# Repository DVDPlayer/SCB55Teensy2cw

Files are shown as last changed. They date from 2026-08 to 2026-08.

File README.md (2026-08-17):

Disclaimer: I'm not a professional programmer or hardware engineer, so go easy on me, use at own risk!

Note: I know that the Teensy 2.0 is quite old, but I used it because I had it and for the challenge!
	Feel free to port it to another device. (Teensy 2.0 also has built-in support for USB-MIDI)

# 🚀 Teensy 2.0 Custom MIDI SBC-55 Controller Firmware (With Hardware Rev.1)

A playback prioritizing serial and USB MIDI firmware for the Teensy 2.0 platform featuring an OLED user interface, rotary encoder control (variable acceleration), Capital Tone Fallback (inverts bank# on fallback), drum and instrument tracking / setting per channel (354 instruments & 10 drum sets - all banks except 126), channel level settings (volume, reverb, chrous), global level settings (volume reverb, chrous), MT-32 emulation initialization (patch, pan, reverb, & pitch bend), display of MT-32 / SC-55 SysEx text messages, display of SC-55 SysEx graphics, send / receive GM & GS SysEx reset, 'analog' volume setting, all notes off Panic! feature, external (software driven) reset button, power-on reset of SCB-55, inactivity screen saver, and a dedicated MIDI hardware pipeline to the SCB-55 waveblaster module.  

Runs from USB (<350mA) or dedicated 6Vdc to 35Vdc input. (see Teensy MOD picture)

This repository contains only the core project firmware and hardware. All third-party dependencies are managed locally to keep the repository structure clean and as lightweight as possible.  

---

## 📦 Required Dependencies

Before compiling, make sure you have the following libraries installed via the Arduino Library Manager:
* **Adafruit_GFX** (OLED Core Graphics)
* **Adafruit_SSD1306** (OLED Driver)
* **Encoder** by Paul Stoffregen (Hardware Rotary Encoder tracking)

*Note: Core libraries (`Arduino.h`, `Wire.h`, `avr/pgmspace.h`, `util/delay.h`) are built into the Teensy / AVR toolchain and do not need to be installed manually.*

---

## 🛠️ Installation & Memory Optimization

To successfully fit the compiled firmware within the microcontroller's limited flash memory, you must disable the default Adafruit splash screen to save code space.

This project is shared under the **GNU GPLv3** license, and since third-party libraries are not hosted directly in this repository, you will need to apply the following optimizations to your local Arduino environment manually:

### Required Tweaks:
1. Locate your local Arduino libraries folder (usually found under `Documents/Arduino/libraries/`).
2. Open the `Adafruit_SSD1306` directory.
3. Open `Adafruit_SSD1306.h` in a text editor.
4. Locate the configuration lines near the top of the file and **uncomment** the splash logo macro definition to match this:
```   
   // Uncomment to disable Adafruit splash logo
   #define SSD1306_NO_SPLASH
```   
5. Open the Arduino `usb_api.h` in a text editor and change `#define USB_MIDI_SYSEX_MAX 64` to at least 79

(Location example: `c:\users\<username>\AppData\Local\Arduino15\packages\teensy\hardware\avr\1.61.0\cores\usb_midi`)

6. Go back one directory to the `cores` folder and open the `teensy` folder and Edit `HardwareSerial.cpp`

7. Find and change the following two lines: (Note: `RX_BUFFER_SIZE` was `64` which is too small for long SysEx)
```
#define RX_BUFFER_SIZE 128 
#define SERIAL1_TX_BUFFER_SIZE 256
```
8. After saving the above files you can compile the project in your Arduino IDE (`Board:Teensy2.0` `USB Type:MIDI`).

---

## 🔌 Hardware Pinout (Basic Info - or if not using my board design)

Connect your components to the **Teensy 2.0** board according to the pinout layout below:

| Component 		| Pin 		| Teensy 2.0 Pin| Notes |
| :--- | :---: | :---: | ---: |
| **SSD1306 OLED**	| GND 		| GND		| (Check pinout as some OLEDs are backwards!)|
|			| VCC 5V	| VCC 5V	|	|
| 			| SCL 		| **5**  (PD0)	| I2C Clock (`Wire.h`)|
| 			| SDA 		| **6**  (PD1)	| I2C Data  (`Wire.h`)|
|			|		|		|	|
| **Rotary Encoder**	| Pin A  	| **1**  (PB1)	| Main rotation pin|
| encoder module used	| Pin B  	| *24**  (PE6)	| Main rotation pin|
|			| Switch 	| **0**  (PB0)	| Encoder push-button switch|
|			| VCC		| VCC		|	|
|			| GND		| GND		|	|
|			|		|		|	|
| **Vol POT 10k-100k**	| Wiper Pin 	| **12** (PD7)	| 'Analog' Output Control (Volume potentiometer)|
| Right Pin		| VCC		| VCC		| (optional part)|
| Left  Pin		| GND		| GND		|	|
|			|		|		|	|
| **Reset Button** 	| Switch Pin 	| **10** (PC7)	| System Reset trigger|
|			| GND		| GND		| (optional part)|
|			|		|		|	|
| **Reset to SCB55**	| Reset Line 	| **2**  (PB2)	| Hardware reset line sent to SCB-55 - pin 26|
|			|		|		|	|
| **Serial MIDI RX** 	| MIDI IN Line	| **RX (Pin 7)**| (PD2) Hardware MIDI input (from H11L1+470Ω pull-up)|
|			|		|		|	|
| **SCB-55 MIDI RX** 	| MIDI OUT Line	| **TX (Pin 8)**| (PD3) MIDI stream to Roland SCB-55 - pin 4|

 Note: 	Pin numbers are programming numbers, add 2 for actual pin number except 24 = pin30, 12 = pin19.
	If you want to use external power and USB, the Teensy 2.0 must be modified. (see Teensy MOD picture)
	The SCB-55 also requires a +/-12V and +5 supply to run correctly along with L/R audio out.

		MIDI Input Example:
<p float="left">
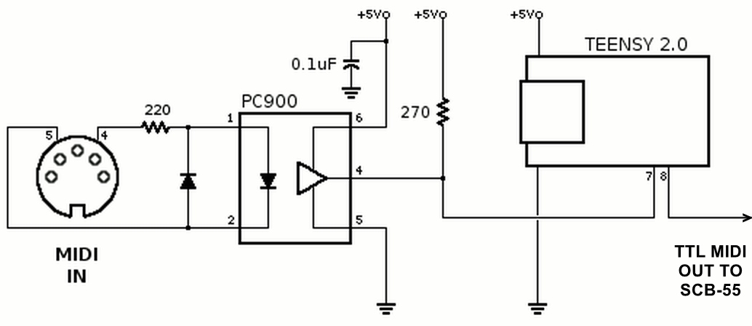
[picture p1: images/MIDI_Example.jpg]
   
</p>
(Note: The Ultra-cheap USB MIDI cables, with the treble clef, will corrupt all SysEx messages.)

---

## 🎹 MIDI & Serial Routing Architecture
* **Serial RX (Receive) :** Dedicated to handling incoming **MIDI In** streams.
* **USB MIDI  (Bi-directional):** to/from Teensy 2.0 (MIDI actions are echoed from UI to host PC)
* **Serial TX (Transmit):** Dedicated to delivering processed **MIDI data to the SCB-55** waveblaster module.

---

## 💻 MENUS, Teensy 2.0 Vusb mod, Rev1 Diode Mod (important) and other pictures

	Arduino IDE Settings
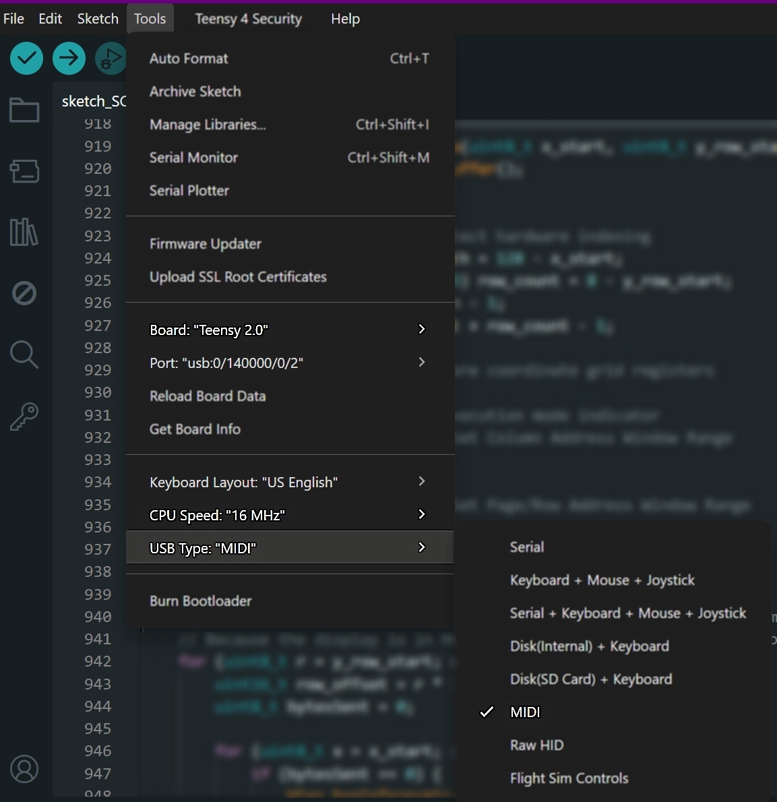
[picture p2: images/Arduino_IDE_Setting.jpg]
  
	 <b>Hardware</b> 
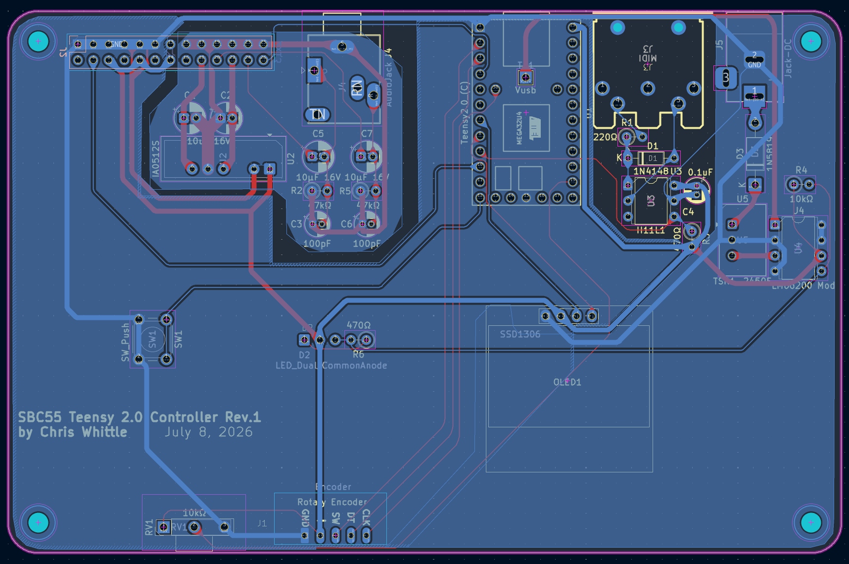
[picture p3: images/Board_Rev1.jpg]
   
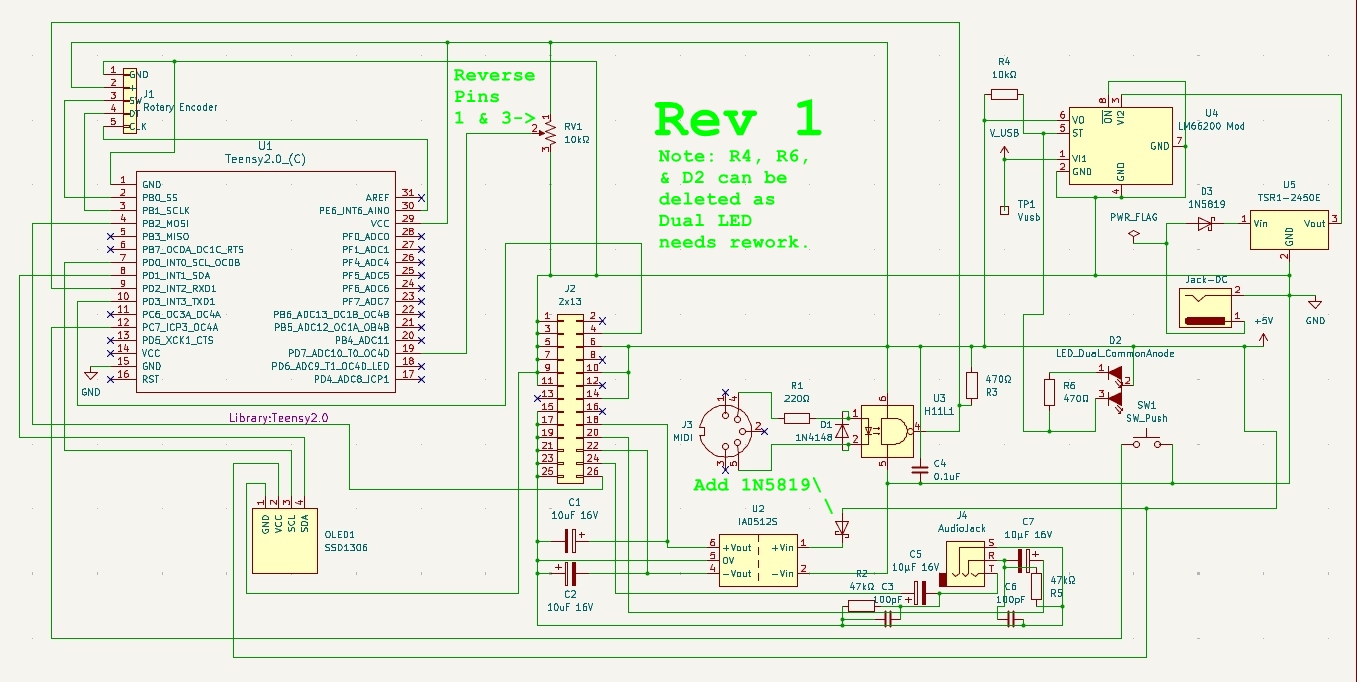
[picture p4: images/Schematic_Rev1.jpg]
   
	 <b>User Interface</b> 

| | |
| :---: | :---: |
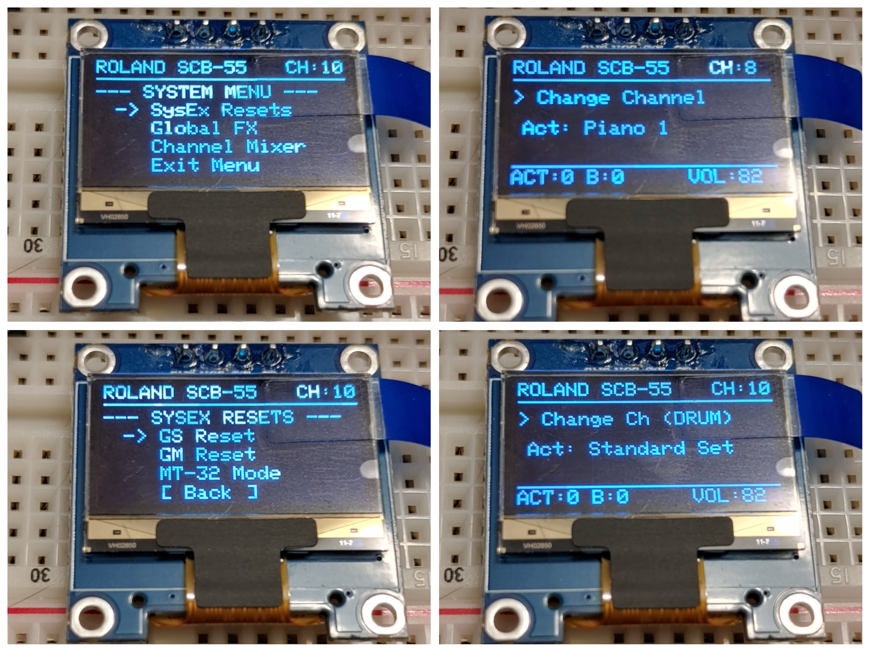
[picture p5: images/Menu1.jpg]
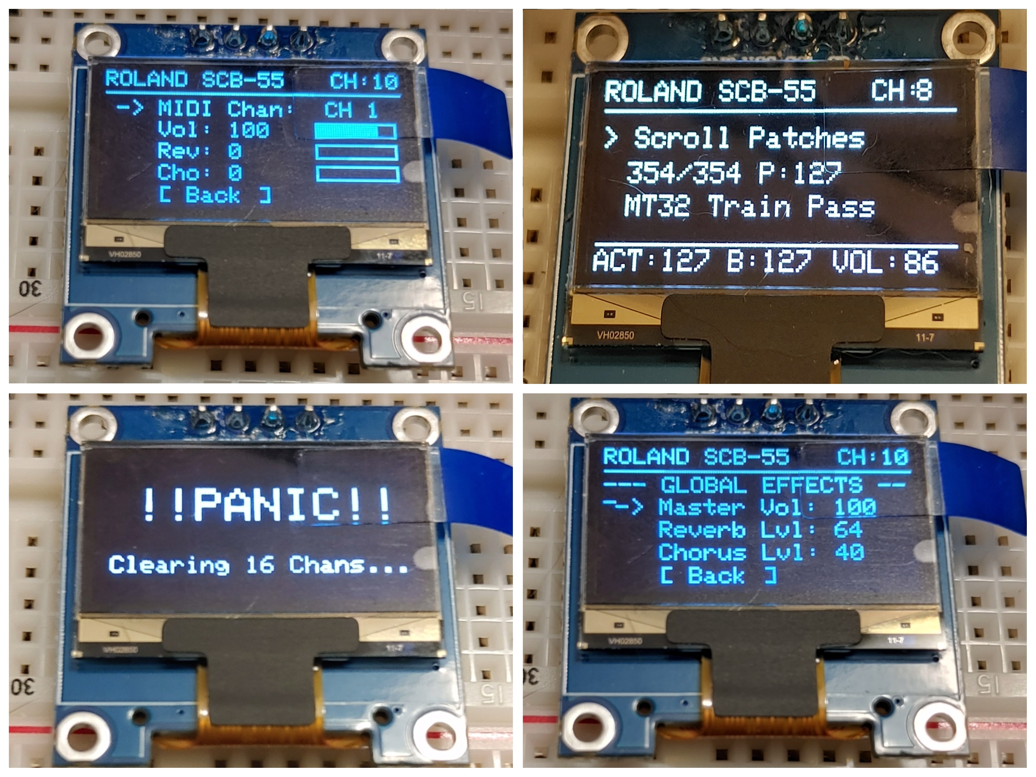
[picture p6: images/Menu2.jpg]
|  |  |
	 Important if using dual power (*Teensy MOD) 
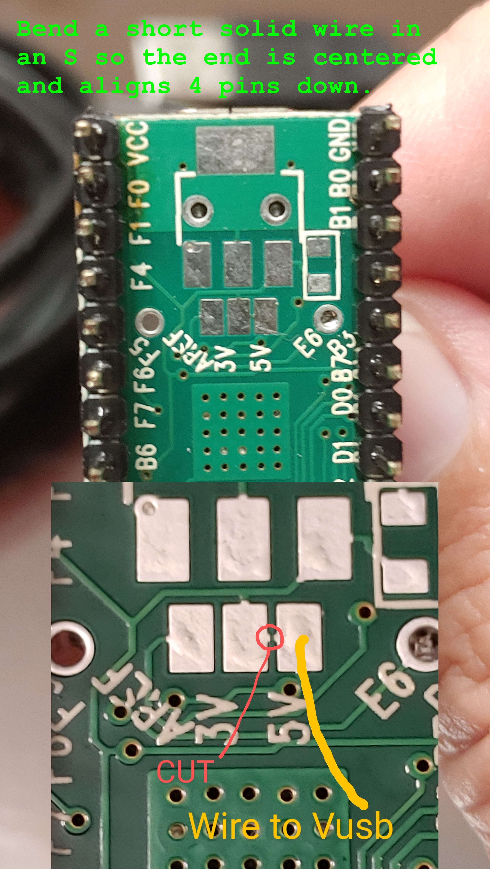
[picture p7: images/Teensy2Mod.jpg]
   
	 <b>Initial Prototype</b> 
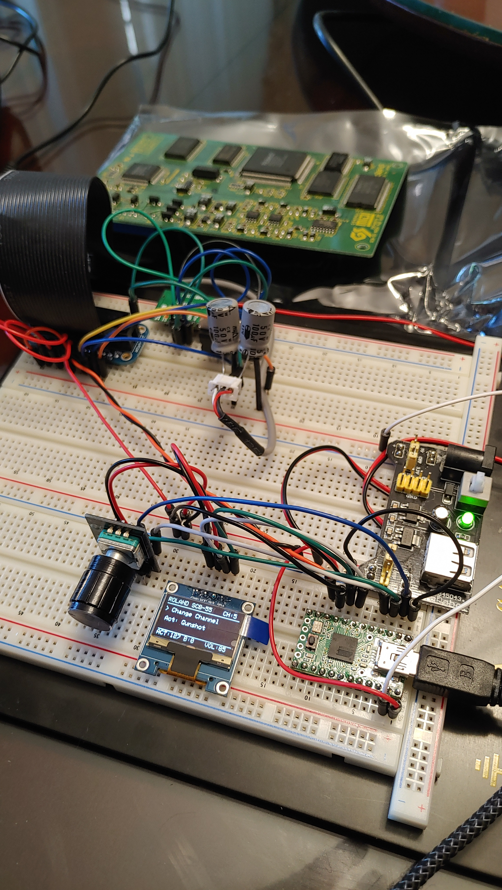
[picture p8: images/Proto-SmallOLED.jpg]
   
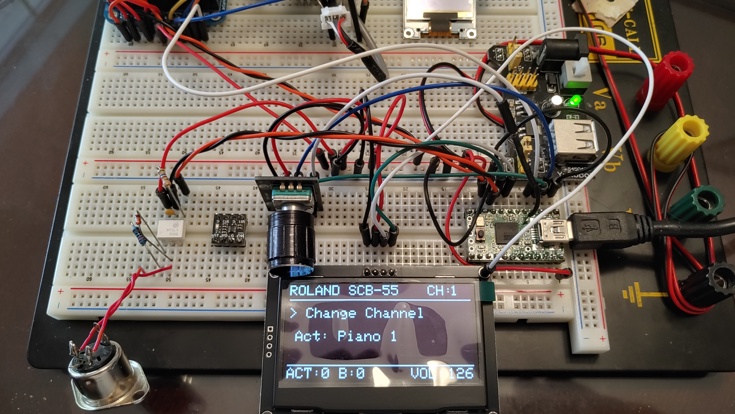
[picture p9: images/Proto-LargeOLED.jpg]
   
 <b>If using rev1 hardware (update coming)</b> 
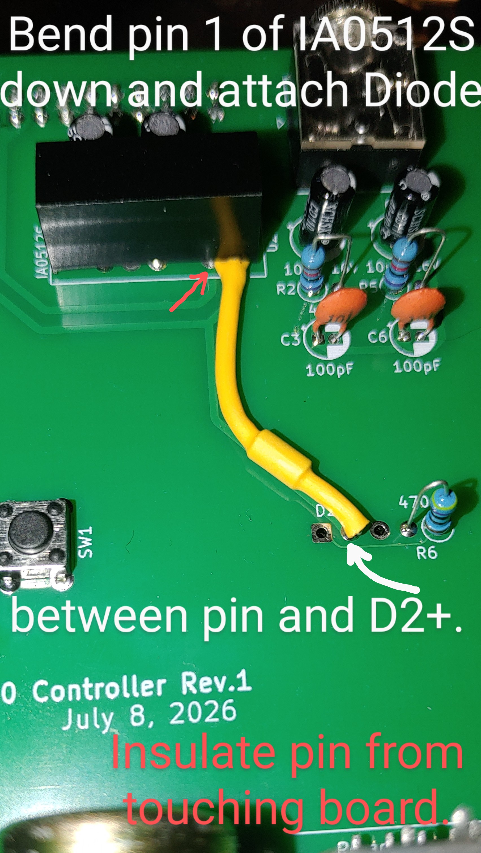
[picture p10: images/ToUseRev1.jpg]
   
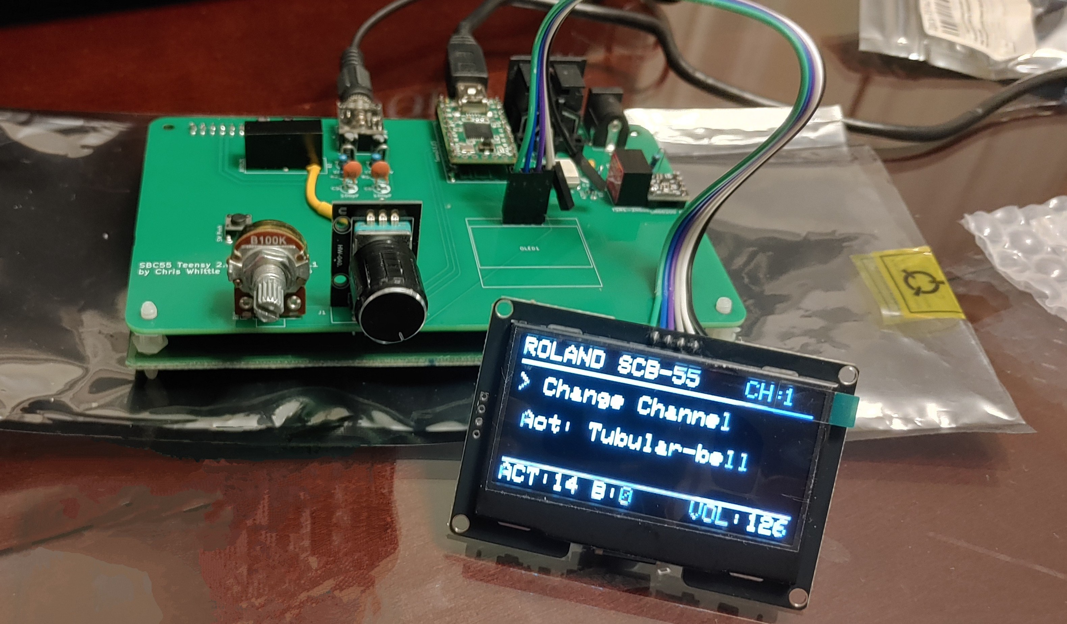
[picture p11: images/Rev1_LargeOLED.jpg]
   

---

## 📄 Credits and other notes

This used: 

Arduino IDE 2.3.10 - [IDE](https://www.arduino.cc/en/software/),  [Teensy2.0](https://www.pjrc.com/teensy/card2a_rev5_web.pdf)

KiCAD 10.0 (Along with several Footprints, please let me know if I missed credit on any), [KiCad](https://github.com/KiCad)

Teensy 2.0 Footprint [XenGi](https://github.com/XenGi/teensy_library)

FreeCAD 1.1.1 (to be used for the 3D case) - [FreeCAD](https://www.freecad.org/)

along with several programs that were very helpful for debug and testing:

The excellent MIDI Player 6.5 by Zoltán Bacskó (Falcosoft) https://falcosoft.hu/

The very impressive Nuked-SC55 emulator which helped verify proper display & behaviour. [Nuked-SC55](https://github.com/nukeykt/Nuked-SC55) 

Along with Roland who created the SCB-55 GS Daughter Board that made this possible.

Other GS/GM daughter boards that use the wavetable connection should be electrically compatible, but the firmware is written for the SCB-55 and would need to be modified to control others properly.  Also the board and corner holes have been sized for the SCB-55 specifically.  Feel free to make your own modifications.

---

## 📜 License

This project is licensed under the **GNU General Public License v3 (GPLv3)**. See the `LICENSE` file in the root of this repository for the full legal text. You are free to share and adapt this code, provided all derivative works remain open-source under the same terms.

## ⚙️ **Third-Party Libraries:** This software compiles dependencies from the **Arduino Core Library Framework** (LGPL-2.1) and the **Adafruit GFX Engine** (BSD 2-Clause). Full attribution terms are listed inside the [`THIRD-PARTY-NOTICES.md`](./THIRD-PARTY-NOTICES.md) file.

---

Please Note:

This is Rev.1, there are some hardware errors (POT wired backwards & I should have used a WRA0512S (not A0512S))
also I'm just about out of code space in the Teensy 2.0, but it does seem to be working quite well (with the mod of adding an inline 1N5819 in front of the A0512S on the 5V line to drop +/-12V to a safe level).  This diode bodge sacrifices the dual colour LED that I was planning, but it wasn't correct anyhow. 
(Don't get AI to 'help' design hardware without verifying results!)

This does work fully from USB only (< 350mA), or from external power with 5 pin MIDI, when connected to USB the MIDI jack is still active and either can be used (one at a time as there is no flow control).  Connecting USB and external power should be safe* as I've used an ORing module to prevent voltage feedback/feedthrough, but currently you will lose USB connection with the host PC (not sure if this can be fixed, but a powered hub can be used for a weak USB port in place of the external power jack).  *As long as the Teensy's `Vusb` is cut and wired to the board!

I plan on addressing the current hardware errors on the board and will see if I can optimize the code further as I do have some inconsistencies and some duplication in the code.  I also have a few more features to add (making the POT re-assignable, and various settings saved to EEPROM, etc.) I would also like to implement the display of bank 126 (but doubt there will be enough code space for this).

Any modifications or suggestions are welcome, please remember that I don't do this professionally and I did enlist AI input / modification for some of my code, so it may not be the best implementation possible. 

Once again, this works for me, but I take no liability or responsibility if any thing blows up or burns down and you assume all responsibility for creating all or parts of this project.

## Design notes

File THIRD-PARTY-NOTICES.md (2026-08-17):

# Third-Party Framework Disclosures

This application links dynamically to runtime frameworks and external graphic/driver modules. The specific license conditions of those independent packages are designated below:

## 1. Arduino Core Platform (`Arduino.h`, `Wire.h`)
* **License:** GNU Lesser General Public License v2.1 (LGPL-2.1)
* **Scope:** Governs foundational hardware abstractions, timing parameters, and internal I2C protocols.

## 2. AVR Toolchain Architecture (`avr/pgmspace.h`, `util/delay.h`)
* **License:** GNU General Public License v2 (GPLv2 with Runtime Exception)
* **Scope:** Standard microcontroller utilities provided via the compiler runtime.

## 3. Adafruit Graphics Suite (`Adafruit_GFX.h`, `Adafruit_SSD1306.h`)
* **License:** BSD 2-Clause License
* **Copyright:** Copyright (c) Adafruit Industries. All rights reserved.

Redistribution and use in source and binary forms, with or without modification, are permitted provided that the following conditions are met:
1. Redistributions of source code must retain the above copyright notice, this list of conditions and the following disclaimer.
2. Redistributions in binary form must reproduce the above copyright notice, this list of conditions and the following disclaimer in the documentation and/or other materials provided with the distribution.

## 4. Quadrature Encoder Decoder (`Encoder.h`)
* **Author:** Paul Stoffregen (PJRC)
* **License:** MIT / Permissive Open Source
* **Scope:** Highly optimized interrupt tracking engine for hardware rotary encoders.

------------------------------------------------------------------------------------
License KiCad
------------------------------------------------------------------------------------

### KiCad Libraries License

The KiCad libraries are licensed under the [Creative Commons CC-BY-SA 4.0 License](https://creativecommons.org/licenses/by-sa/4.0/legalcode), with the following exception:

---------

_To the extent that the creation of electronic designs that use 'Licensed Material' can be considered to be 'Adapted Material', then the copyright holder waives article 3 of the license with respect to these designs and any generated files which use data provided as part of the 'Licensed Material'._

---------

You can read more about KiCad library licensing [here](http://kicad.org/libraries/license).

**What does this mean?**

KiCad libraries are licensed in such a way to ensure free use of library data for commercial, closed, and non-commercial projects without restriction. KiCad does not wish to exert any control over designs produced using the library data, or force users to reveal proprietary information contained in their designs. Neither do we wish to force users to attribute the KiCad libraries _within their design_.

Use of the library data in a project does not (by itself) require that the design or any files generated from the design are licensed under the CC-BY-SA 4.0 License. You are free to use the library data in your own projects without the obligation to share your project files under this or any other license agreement.

However, if you wish to redistribute the KiCad libraries, or parts thereof (including in modified form) as a collection then the exception above does not apply. Redistributed library collections must be shared under the same license agreement. Under these circumstances, the libraries must also retain attribution information, including the license documents which are distributed with the library files.

----------------------

**Warranty**

The KiCad libraries are provided in the hope that they will be useful, but are provided without warranty of any kind, express or implied.

The KiCad libraries are compiled by the KiCad community - if you find an error in the library data, please help the community and contribute a fix!

------------------------------------------------------------------------------------
License Teensy 2.0 Library files for KiCad
------------------------------------------------------------------------------------

The MIT License (MIT)
Copyright (c) 2015 Ricardo Band
Permission is hereby granted, free of charge, to any person obtaining a copy
of this software and associated documentation files (the "Software"), to deal
in the Software without restriction, including without limitation the rights
to use, copy, modify, merge, publish, distribute, sublicense, and/or sell
copies of the Software, and to permit persons to whom the Software is
furnished to do so, subject to the following conditions:
The above copyright notice and this permission notice shall be included in all
copies or substantial portions of the Software.
THE SOFTWARE IS PROVIDED "AS IS", WITHOUT WARRANTY OF ANY KIND, EXPRESS OR
IMPLIED, INCLUDING BUT NOT LIMITED TO THE WARRANTIES OF MERCHANTABILITY,
FITNESS FOR A PARTICULAR PURPOSE AND NONINFRINGEMENT. IN NO EVENT SHALL THE
AUTHORS OR COPYRIGHT HOLDERS BE LIABLE FOR ANY CLAIM, DAMAGES OR OTHER
LIABILITY, WHETHER IN AN ACTION OF CONTRACT, TORT OR OTHERWISE, ARISING FROM,
OUT OF OR IN CONNECTION WITH THE SOFTWARE OR THE USE OR OTHER DEALINGS IN THE
SOFTWARE.

------------------------------------------------------------------------------------

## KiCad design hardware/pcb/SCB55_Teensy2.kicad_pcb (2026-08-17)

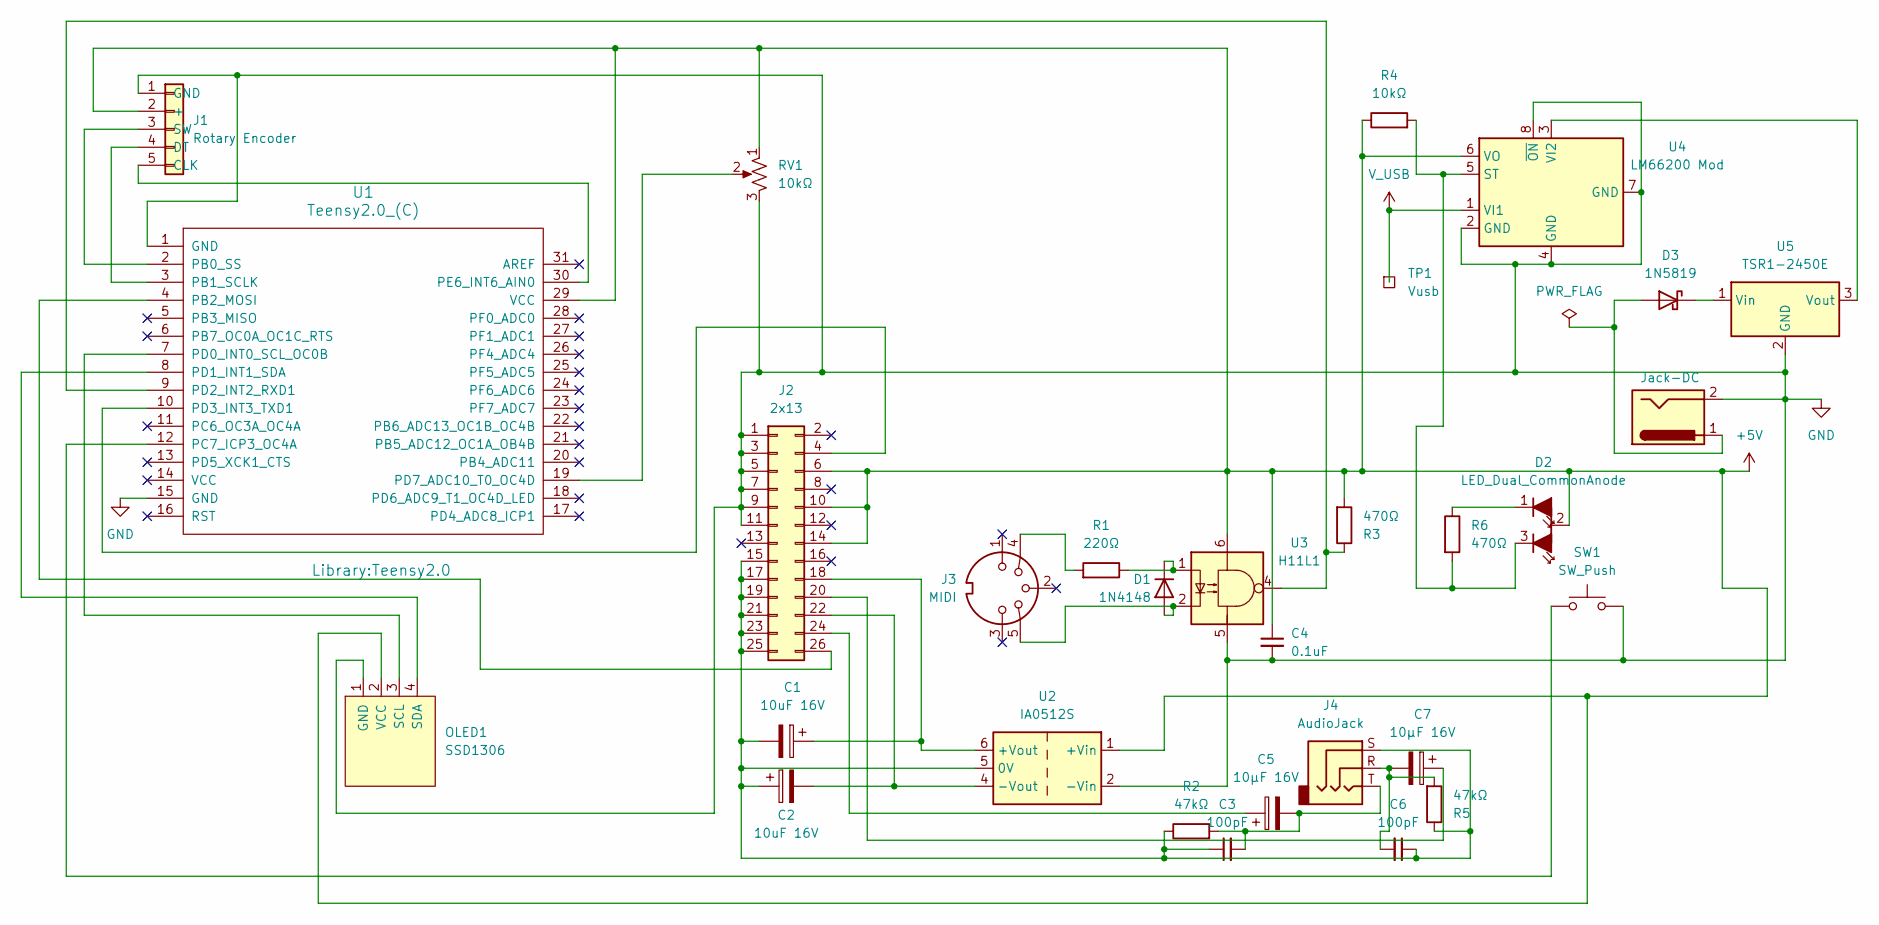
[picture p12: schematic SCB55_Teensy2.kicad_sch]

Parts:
C1, C2: 10uF 16V; CP_Radial_D5.0mm_P2.00mm
C3, C6: 100pF; CP_Radial_D4.0mm_P1.50mm
C4: 0.1uF; CP_Radial_D4.0mm_P1.50mm
C5, C7: 10µF 16V; CP_Radial_D5.0mm_P2.00mm
D1: 1N4148; D_DO-35_SOD27_P7.62mm_Horizontal
D2: LED_Dual_CommonAnode; LED_3Pin_2.54mm
D3: 1N5819; D_DO-41_SOD81_P10.16mm_Horizontal
J1: Rotary Encoder; Rotary Encoder Board with Switch
J2: 2x13; PinHeader_2x13_P2.54mm_Vertical
J3: MIDI; DIN5_MIDI
J4: AudioJack; Jack_3.5mm_Ledino_KB3SPRS_Horizontal
J5: Jack-DC; BarrelJack_Horizontal
OLED1: SSD1306; 128x64OLED
R1: 220Ω; R_Axial_DIN0207_L6.3mm_D2.5mm_P2.54mm_Vertical
R2, R5: 47kΩ; R_Axial_DIN0207_L6.3mm_D2.5mm_P2.54mm_Vertical
R3, R6: 470Ω; R_Axial_DIN0207_L6.3mm_D2.5mm_P2.54mm_Vertical
R4: 10kΩ; R_Axial_DIN0207_L6.3mm_D2.5mm_P2.54mm_Vertical
RV1: 10kΩ; WH148 Potentiometer 3 Pin
SW1: SW_Push; SW_PUSH_6mm
TP1: Vusb; TestPoint_THTPad_2.0x2.0mm_Drill1.0mm
U1: Teensy2.0_(C); Teensy2.0
U2: IA0512S; Converter_DCDC_XP_POWER-IAxxxxS_THT
U3: H11L1; DIP-6_W7.62mm
U4: LM66200 Mod; DIP-8_W7.62mm
U5: TSR1-2450E; Converter_DCDC_TRACO_TSR1-xxxxE_THT

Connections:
+5V: C4.1, D2.2 (A), J1.2 (+), J2.6, J2.10, J2.14, OLED1.2 (VCC), R3.2, R4.1, RV1.1, U1.29 (VCC), U2.1 (+Vin), U3.6, U4.6 (VO)
GND: C4.2, J1.1 (GND), J2.1, J2.3, J2.5, J2.7, J2.9, J2.11, J5.2, OLED1.1 (GND), RV1.3, SW1.2, U1.1 (GND), U1.15 (GND), U2.2 (-Vin), U3.5, U4.2 (GND), U4.4 (GND), U4.7 (GND), U4.8 (~ON), U5.2 (GND)
unnamed: C3.2, C5.2, J4.T, R2.2
unnamed: C6.2, C7.2, J4.R, R5.2
unnamed: D1.2 (A), J3.5, U3.2
unnamed: D1.1 (K), R1.1, U3.1
unnamed: D2.1 (K1), R6.1
unnamed: D2.3 (K2), R4.2, R6.2, U4.5 (ST)
unnamed: D3.2 (A), J5.1
unnamed: D3.1 (K), U5.1 (Vin)
unnamed: J1.5 (CLK), U1.30 (PE6_INT6_AIN0)
unnamed: J1.4 (DT), U1.3 (PB1_SCLK)
unnamed: J1.3 (SW), U1.2 (PB0_SS)
unnamed: J2.4, U1.10 (PD3_INT3_TXD1)
unnamed: C1.2, C2.1, C3.1, C6.1, J2.15, J2.17, J2.19, J2.21, J2.23, J2.25, J4.S, R2.1, R5.1, U2.5 (0V)
unnamed: C1.1, J2.18, U2.6 (+Vout)
unnamed: C7.1, J2.20
unnamed: C2.2, J2.22, U2.4 (-Vout)
unnamed: C5.1, J2.24
unnamed: J2.26, U1.4 (PB2_MOSI)
unnamed: J3.4, R1.2
unnamed: OLED1.3 (SCL), U1.7 (PD0_INT0_SCL_OC0B)
unnamed: OLED1.4 (SDA), U1.8 (PD1_INT1_SDA)
unnamed: SW1.1, U1.12 (PC7_ICP3_OC4A)
unnamed: R3.1, U1.9 (PD2_INT2_RXD1), U3.4
unnamed: RV1.2, U1.19 (PD7_ADC10_T0_OC4D)
unnamed: U4.3 (VI2), U5.3 (Vout)
V_USB: TP1.1 (1_1), U4.1 (VI1)

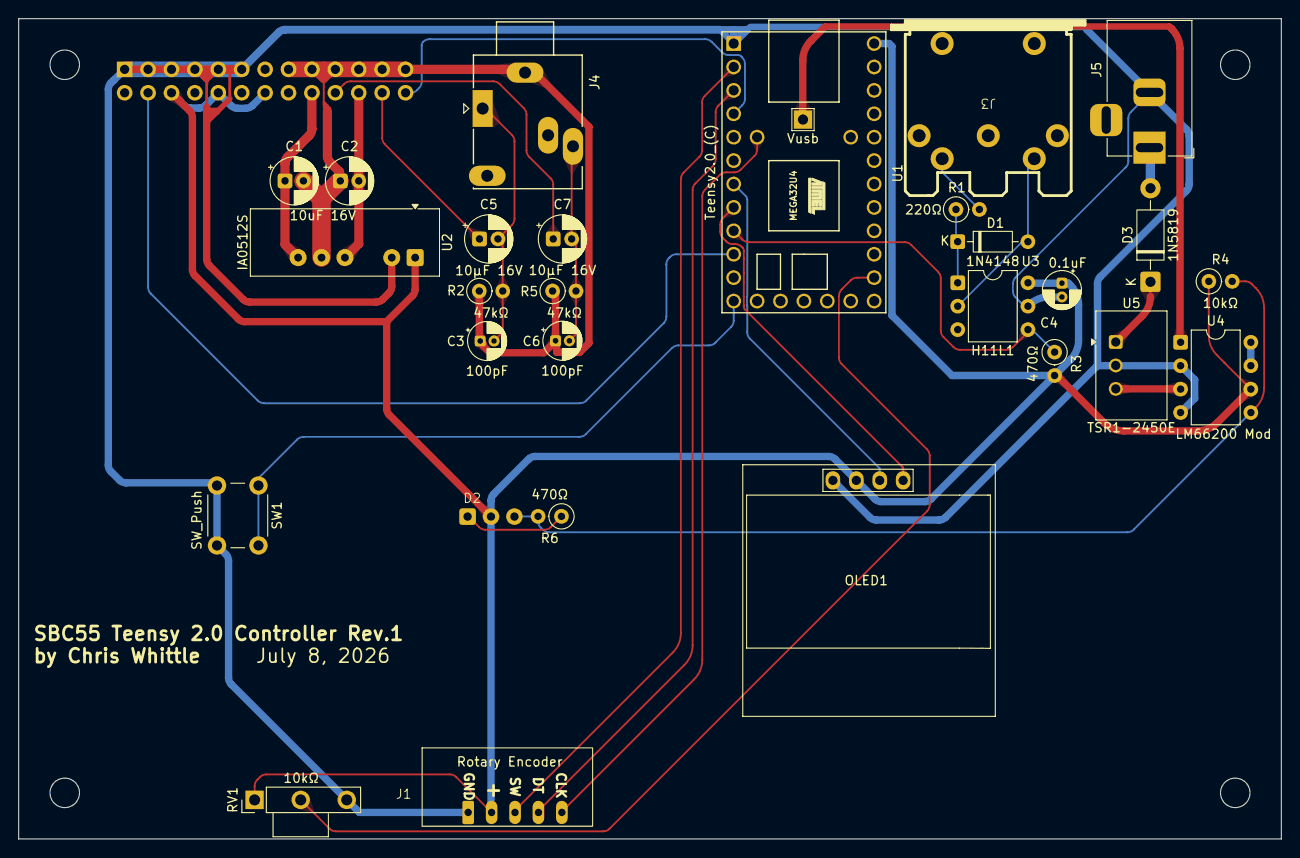
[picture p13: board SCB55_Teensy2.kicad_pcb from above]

Board: 2 copper layers, 137.0 x 89.0 mm, 30 parts (1 on the bottom side), 28 nets.

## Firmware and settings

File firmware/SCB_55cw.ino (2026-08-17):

#include <Arduino.h>
#include <Wire.h>
#include <Adafruit_GFX.h>
//#define SSD1306_NO_SPLASH - NG Change in Adafruit_SSD1306.h
#include <Adafruit_SSD1306.h>
#include <Encoder.h>
#include <avr/pgmspace.h>
#include <util/delay.h>

// =========================================================================
// 1. HARDWARE PIN CONFIGURATION
// =========================================================================
#define ENC_SW_PIN       0   // PB0: Encoder Push Button
#define ENC_A_PIN        1   // PB1: Encoder Phase A
#define ENC_B_PIN       24   // PE6: Encoder Phase B - Changed to INT6
#define SCB55_RESET_PIN  2   // PB2: Connected to SCB-55 !Reset Line
#define RESET_BUTTON_PIN 10  // PC7: Pin connected to external reset button
#define OLED_SCL         5   // PD0: I2C SCL
#define OLED_SDA         6   // PD1: I2C SDA
#define POT_PIN         12   // A10:  Volume Potentiometer Wiper
#define SERIAL1_TX_BUFFER_SIZE 256 // (change in teensy/HardwareSerial.cpp)
#define RX_BUFFER_SIZE 128 // (change in teensy/HardwareSerial.cpp) was 64
//#define USB_MIDI_SYSEX_MAX 79 change in ../usb_midi/usb_api.h should be >75 (for screen pixel data)

#define SCREEN_WIDTH 128
#define SCREEN_HEIGHT 64
#define OLED_RESET    -1 
Adafruit_SSD1306 display(SCREEN_WIDTH, SCREEN_HEIGHT, &Wire, OLED_RESET, 400000UL, 400000UL);

Encoder myEnc(ENC_A_PIN, ENC_B_PIN);

// =========================================================================
// 2. DATA STRUCTURES & PROGMEM LOOKUP TABLES
// =========================================================================
struct InstrumentAllocation {
    uint8_t bank;
    uint8_t program;
    char name[16]; 
};
// Melodic Instruments Table (354 sounds for Chans 1-9, 11-16)
const InstrumentAllocation scb55_bank[354] PROGMEM = {
    // SECTION 1: GENERAL MIDI CAPITAL TONES (BANK 0) - [128 Tones] Fixed
    {0, 0, "Piano 1"},        {0, 1, "Piano 2"},        {0, 2, "Piano 3"},        {0, 3, "Honky-tonk"},
    {0, 4, "E.Piano 1"},      {0, 5, "E.Piano 2"},      {0, 6, "Harpsichord"},    {0, 7, "Clav."},
    {0, 8, "Celesta"},        {0, 9, "Glockenspiel"},   {0, 10, "Music Box"},     {0, 11, "Vibraphone"},
    {0, 12, "Marimba"},       {0, 13, "Xylophone"},     {0, 14, "Tubular-bell"},  {0, 15, "Santur"},
    {0, 16, "Organ 1"},       {0, 17, "Organ 2"},       {0, 18, "Organ 3"},       {0, 19, "Church Organ"},
    {0, 20, "Reed Organ"},    {0, 21, "Accordion Fr."}, {0, 22, "Harmonica"},     {0, 23, "Bandoneon"},
    {0, 24, "Nylon-str.Gt"},  {0, 25, "Steel-str.Gt"},  {0, 26, "Jazz Guitar"},   {0, 27, "Clean Guitar"},
    {0, 28, "Muted Guitar"},  {0, 29, "Overdrive Gt"},  {0, 30, "Distortion Gt"}, {0, 31, "Gt.Harmonics"},
    {0, 32, "Acoustic Bass"}, {0, 33, "Fingered Bass"}, {0, 34, "Picked Bass"},   {0, 35, "Fretless Bass"},
    {0, 36, "Slap Bass 1"},   {0, 37, "Slap Bass 2"},   {0, 38, "Synth Bass 1"},  {0, 39, "Synth Bass 2"},
    {0, 40, "Violin"},        {0, 41, "Viola"},         {0, 42, "Cello"},         {0, 43, "Contrabass"},
    {0, 44, "Tremolo Str"},   {0, 45, "Pizzicato Str"}, {0, 46, "OrchestralHarp"},{0, 47, "Timpani"},
    {0, 48, "String Ens. 1"}, {0, 49, "String Ens. 2"}, {0, 50, "SynthStrings 1"},{0, 51, "SynthStrings 2"},
    {0, 52, "Choir Aahs"},    {0, 53, "Voice Oohs"},    {0, 54, "Synth Vox"},     {0, 55, "Orchestra Hit"},
    {0, 56, "Trumpet"},       {0, 57, "Trombone"},      {0, 58, "Tuba"},          {0, 59, "Muted Trumpet"},
    {0, 60, "French Horn"},   {0, 61, "Brass Section1"},{0, 62, "Synth Brass 1"}, //Fixed shift
    {0, 63, "Synth Brass 2"}, {0, 64, "Soprano Sax"},   {0, 65, "Alto Sax"},      {0, 66, "Tenor Sax"},
    {0, 67, "Baritone Sax"},  {0, 68, "Oboe"},          {0, 69, "English Horn"},  {0, 70, "Bassoon"},
    {0, 71, "Clarinet"},      {0, 72, "Piccolo"},       {0, 73, "Flute"},         {0, 74, "Recorder"},
    {0, 75, "Pan Flute"},     {0, 76, "Bottle Blow"},   {0, 77, "Shakuhachi"},    {0, 78, "Whistle"},
    {0, 79, "Ocarina"},       {0, 80, "Square Wave"},   {0, 81, "Saw Wave"},      {0, 82, "Syn Calliope"},
    {0, 83, "Chiffer Lead"},  {0, 84, "Charang"},       {0, 85, "Solo Vox"},      {0, 86, "5th Saw Wave"},
    {0, 87, "Bass & Lead"},   {0, 88, "Fantasia"},      {0, 89, "Warm Pad"},      {0, 90, "Polysynth"},
    {0, 91, "Space Voice"},   {0, 92, "Bowed Glass"},   {0, 93, "Metal Pad"},     {0, 94, "Halo Pad"},
    {0, 95, "Sweep Pad"},     {0, 96, "Ice Rain"},      {0, 97, "Soundtrack"},    {0, 98, "Crystal"},
    {0, 99, "Atmosphere"},    {0, 100, "Brightness"},   {0, 101, "Goblin"},       {0, 102, "Echo Drops"},
    {0, 103, "Star Theme"},   {0, 104, "Sitar"},        {0, 105, "Banjo"},        {0, 106, "Shamisen"},
    {0, 107, "Koto"},         {0, 108, "Kalimba"},      {0, 109, "Bagpipe"},      {0, 110, "Fiddle"},
    {0, 111, "Shanai"},       {0, 112, "Tinkle Bell"},  {0, 113, "Agogo"},        {0, 114, "Steel Drums"},
    {0, 115, "Woodblock"},    {0, 116, "Taiko Drum"},   {0, 117, "Melodic Tom"},  {0, 118, "Synth Drum"},
    {0, 119, "ReverseCymbal"},{0, 120, "Gt.Fret Noise"},{0, 121, "Breath Noise"}, {0, 122, "Seashore"},
    {0, 123, "Bird Tweet"},   {0, 124, "Telephone 1"},  {0, 125, "Helicopter"},   {0, 126, "Applause"},
    {0, 127, "Gunshot"},

    // SECTION 2: ROLAND GS VARIATION TONES (BANKS 1 - 64) - [98 Tones] Fixed & Sorted (98)
    {1, 38, "Synth Bass 101"}, {1, 57, "Trombone 2"},     {1, 60, "French Horn 2"},  {1, 80, "Square"}, 
    {1, 81, "Saw"},            {1, 98, "Syn Mallet"},     {1, 102, "Echo Bell"},     {1, 104, "Sitar 2"}, 
    {1, 120, "Gt. Cut Noise"}, {1, 121, "Fl.Key Click"},  {1, 122, "Rain"},          {1, 123, "Dog Bark"}, 
    {1, 124, "Telephone 2"},   {1, 125, "Car Engine"},    {1, 126, "Laughing"},      {1, 127, "Machine Gun"}, 
    {2, 102, "Echo Pan"},      {2, 120, "String Slap"},   {2, 122, "Thunder"},       {2, 123, "Horse Gallop"}, 
    {2, 124, "Door Creaking"}, {2, 125, "Car Stop"},      {2, 126, "Screaming"},     {2, 127, "Lasergun"}, 
    {3, 122, "Wind"},          {3, 123, "Bird Tweet 2"},  {3, 124, "Door Shut"},     {3, 125, "Car Pass"}, 
    {3, 126, "Punch"},         {3, 127, "Explosion"},     {4, 122, "Stream"},        {4, 124, "Scratch Mix"}, 
    {4, 125, "Car Crash"},     {4, 126, "Heartbeat"},     {5, 122, "Bubble"},        {5, 124, "Wind Chime"}, 
    {5, 125, "Siren"},         {5, 126, "Footsteps"},     {6, 125, "Train"},         {7, 125, "Jetplane"}, 
    {8, 0, "Piano 1w"},        {8, 1, "Piano 2w"},        {8, 2, "Piano 3w"},        {8, 3, "Honky-tonk w"}, 
    {8, 4, "Detuned EP 1"},    {8, 5, "Detuned EP 2"},    {8, 6, "Coupled Hps."},    //{8, 7, "Clav. w"},
    {8, 11, "Vibraphone w"},   {8, 12, "Marimba w"},      {8, 14, "Church Bell"},    {8, 16, "Detuned Organ 1"}, 
    {8, 17, "Detuned Organ 2"},{8, 19, "Church Organ 2"}, {8, 21, "Accordion It."},  {8, 24, "Ukulele"}, 
    {8, 25, "12-str.Guitar"},  {8, 26, "Hawaiian Gt."},   {8, 27, "Chorus Gt."},     {8, 28, "Funk Gt."}, 
    {8, 30, "Feedback Gt."},   {8, 31, "Gt. Feedback"},   {8, 38, "Synth Bass 3"},   {8, 39, "Synth Bass 4"}, 
    {8, 40, "Slow Violin"},    {8, 48, "Orchestra"},      {8, 50, "Synth Strings3"}, {8, 61, "Brass 2"}, 
    {8, 62, "Synth Brass 3"},  {8, 63, "Synth Brass 4"},  {8, 80, "Sine Wave"},      {8,81, "Doctor Solo"}, {8, 107, "Taisho Koto"}, 
    {8, 115, "Castanets"},     {8, 116, "Concert BassDr"},{8, 117, "Melo. Tom 2"},   {8, 118, "808 Tom"}, 
    {8, 125, "Starship"},      {9, 14, "Carillon"},       {9, 118, "Elec Perc"},     {9, 125, "Burst Noise"}, 
    {16, 0, "Piano 1d"},       {16, 4, "E.Piano 1v"},     {16, 5, "E.Piano 2v"},     {16, 6, "Harpsichord w"}, 
    {16, 16, "60s Organ 1"},   {16, 19, "Church Organ 3"},{16, 24, "Nylon Gt. o"},   {16, 25, "Mandolin"}, 
    {16, 28, "Funk Gt. 2"},    {16, 39, "Rubber Bass"},   {16, 62, "Analog Brass 1"},{16, 63, "Analog Brass 2"}, 
    {24, 4, "60s E.Piano"},    {24, 6, "Harpsi.o"},       {32, 16, "Organ 4"},       {32, 17, "Organ 5"}, 
    {32, 24, "Nylon Gt. 2"},   {32, 52, "Choir Aahs 2"}, 

    // SECTION 3: VINTAGE MT-32 LEGACY EMULATION (BANK 127) - [128 Tones] Fixed
    {127, 0, "MT32 AcouPiano1"},  {127, 1, "MT32 AcouPiano2"},   {127, 2, "MT32 AcouPiano3"},  {127, 3, "MT32 ElecPiano1"},
    {127, 4, "MT32 ElecPiano2"},  {127, 5, "MT32 ElecPiano3"},   {127, 6, "MT32 ElecPiano4"},  {127, 7, "MT32 Honkytonk"},
    {127, 8, "MT32 Elec Org 1"},  {127, 9, "MT32 Elec Org 2"},   {127, 10, "MT32 Elec Org 3"}, {127, 11, "MT32 Elec Org 4"},
    {127, 12, "MT32 Pipe Org 1"}, {127, 13, "MT32 Pipe Org 2"},  {127, 14, "MT32 Pipe Org 3"}, {127, 15, "MT32 Accordion"},
    {127, 16, "MT32 Harpsi 1"},   {127, 17, "MT32 Harpsi 2"},    {127, 18, "MT32 Harpsi 3"},   {127, 19, "MT32 Clavi 1"},
    {127, 20, "MT32 Clavi 2"},    {127, 21, "MT32 Clavi 3"},     {127, 22, "MT32 Celesta 1"},  {127, 23, "MT32 Celesta 2"},
    {127, 24, "MT32 Syn Brass1"}, {127, 25, "MT32 Syn Brass2"},  {127, 26, "MT32 Syn Brass3"}, {127, 27, "MT32 Syn Brass4"},
    {127, 28, "MT32 Syn Bass 1"}, {127, 29, "MT32 Syn Bass 2"},  {127, 30, "MT32 Syn Bass 3"}, {127, 31, "MT32 Syn Bass 4"},
    {127, 32, "MT32 Fantasy"},    {127, 33, "MT32 Harmo Pan"},   {127, 34, "MT32 Chorale"},    {127, 35, "MT32 Glasses"},
    {127, 36, "MT32 Soundtrack"}, {127, 37, "MT32 Atmosphere"},  {127, 38, "MT32 Warm Bell"},  {127, 39, "MT32 Funny Vox"},
    {127, 40, "MT32 Echo Bell"},  {127, 41, "MT32 Ice Rain"},    {127, 42, "MT32 Oboe 2001"},  {127, 43, "MT32 Echo Pan"},
    {127, 44, "MT32 DoctorSolo"}, {127, 45, "MT32 SchoolDaze"},  {127, 46, "MT32 Bellsinger"}, {127, 47, "MT32 SquareWave"},
    {127, 48, "MT32 Str Sect 1"}, {127, 49, "MT32 Str Sect 2"},  {127, 50, "MT32 Str Sect 3"}, {127, 51, "MT32 Pizzicato"},
    {127, 52, "MT32 Violin 1"},   {127, 53, "MT32 Violin 2"},    {127, 54, "MT32 Cello 1"},    {127, 55, "MT32 Cello 2"},
    {127, 56, "MT32 Contrabass"}, {127, 57, "MT32 Harp 1"},      {127, 58, "MT32 Harp 2"},     {127, 59, "MT32 Guitar 1"},
    {127, 60, "MT32 Guitar 2"},   {127, 61, "MT32 Elec Gtr 1"},  {127, 62, "MT32 Elec Gtr 2"}, {127, 63, "MT32 Sitar"},
    {127, 64, "MT32 Acou Bass1"}, {127, 65, "MT32 Acou Bass2"},  {127, 66, "MT32 Elec Bass1"}, {127, 67, "MT32 Elec Bass2"},
    {127, 68, "MT32 Slap Bass1"}, {127, 69, "MT32 Slap Bass2"},  {127, 70, "MT32 Fretless 1"}, {127, 71, "MT32 Fretless 2"},
    {127, 72, "MT32 Flute 1"},    {127, 73, "MT32 Flute 2"},     {127, 74, "MT32 Piccolo 1"},  {127, 75, "MT32 Piccolo 2"},
    {127, 76, "MT32 Recorder"},   {127, 77, "MT32 Pan Pipes"},   {127, 78, "MT32 Sax 1"},      {127, 79, "MT32 Sax 2"},
    {127, 80, "MT32 Sax 3"},      {127, 81, "MT32 Sax 4"},       {127, 82, "MT32 Clarinet 1"}, {127, 83, "MT32 Clarinet 2"},
    {127, 84, "MT32 Oboe"},       {127, 85, "MT32 Engl Horn"},   {127, 86, "MT32 Bassoon"},    {127, 87, "MT32 Harmonica"},
    {127, 88, "MT32 Trumpet 1"},  {127, 89, "MT32 Trumpet 2"},   {127, 90, "MT32 Trombone 1"}, {127, 91, "MT32 Trombone 2"},
    {127, 92, "MT32 Fr Horn 1"},  {127, 93, "MT32 Fr Horn 2"},   {127, 94, "MT32 Tuba"},       {127, 95, "MT32 Brs Sect 1"},
    {127, 96, "MT32 Brs Sect 2"}, {127, 97, "MT32 Vibe 1"},      {127, 98, "MT32 Vibe 2"},     {127, 99, "MT32 Syn Mallet"},
    {127, 100, "MT32 Windbell"},  {127, 101, "MT32 Glock"},      {127, 102, "MT32 Tube Bell"}, {127, 103, "MT32 Xylophone"},
    {127, 104, "MT32 Marimba"},   {127, 105, "MT32 Koto"},       {127, 106, "MT32 Sho"},       {127, 107, "MT32 Shakuhachi"},
    {127, 108, "MT32 Whistle 1"}, {127, 109, "MT32 Whistle 2"},  {127, 110, "MT32 Bottleblow"},{127, 111, "MT32 Breathpipe"},
    {127, 112, "MT32 Timpani"},   {127, 113, "MT32 MelodicTom"}, {127, 114, "MT32 Deep Snare"},{127, 115, "MT32 Elec Perc1"},
    {127, 116, "MT32 Elec Perc2"},{127, 117, "MT32 Taiko"},      {127, 118, "MT32 Taiko Rim"}, {127, 119, "MT32 Cymbal"},
    {127, 120, "MT32 Castanets"}, {127, 121, "MT32 Triangle"},   {127, 122, "MT32 Orche Hit"}, {127, 123, "MT32 Telephone"},
    {127, 124, "MT32 Bird 2"},    {127, 125, "MT32 1 Note Jam"}, {127, 126, "MT32 Water Bell"},{127, 127, "MT32 JungleTune"}
};
// Roland GS Percussion Sets Table (Ch 10 Exclusive Map) - [10 Sets]
const InstrumentAllocation scb55_drum_kits[10] PROGMEM = {
    {0, 0,  "Standard Set"},
    {0, 8,  "Room Set"},
    {0, 16, "Power Set"},
    {0, 24, "Electronic Set"},
    {0, 25, "TR-808 Set"},
    {0, 32, "Jazz Set"},
    {0, 40, "Brush Set"},
    {0, 48, "Orchestra Set"},
    {0, 56, "SFX Set"},
    {0, 127, "CM-64/32L Set"}
};

// =========================================================================
// 3. GLOBAL UI STATE MANAGEMENT VARIABLES
// =========================================================================
enum MenuMode { BROWSE_PATCH, SET_CHANNEL, MAIN_SYSTEM_MENU, SYSEX_RESETS_MENU, FX_SETTINGS_MENU, CHAN_FX_MENU };
uint8_t currentMode = SET_CHANNEL; 

int cursorIndex = 0;          
int activeIndex = 0;          
uint8_t currentChannel = 1;   
uint8_t lastChannel = 0;   //for display control of Channel / Patch screen
uint8_t currentVolume = 0;    
int lastAnalogValue = 0; 
uint16_t lastAnalogPoll = 0;
char message[21]; 

//Serial1 SysEx Handling
#define MIDI_SYSEX_START 0xF0
#define MIDI_SYSEX_END   0xF7
#define MAX_SYSEX_BUF    80 // Safeguard against buffer overflows
uint8_t sysExBuffer[MAX_SYSEX_BUF];
uint8_t sysExIndex = 0;
bool isRecordingSysEx = false;

//USB MIDI TX Buffer Status
// Safe, non-blocking check for Teensy 2.0 MIDI hardware buffer readiness
#define USB_MIDI_READY ([]() -> bool { \
    uint8_t current_endpoint = UENUM; \
    UENUM = 4; \
    uint16_t timeout = 600; \
    while (!(UEINTX & (1 << RWAL))) { \
        if (--timeout == 0) { \
            UENUM = current_endpoint; \
            return false; /* Host is not listening (Power-only mode) */ \
            break; \
        } \
    } \
    UENUM = current_endpoint; \
    return true; /* Buffer is free to accept data */ \
}())

// Screen Refresh Limiter for UI
const uint16_t refreshRateMaxMs = 666; // 333mS = 3 updates a second
uint16_t lastScreenUpdateTime = 0;

// Non-blocking screen saver configurations
unsigned long lastMidiMessageTime = 0;
const unsigned long messageTimeoutMs = 5000; // 5 seconds timeout limit
bool isDisplayActive = false;
bool activity = true; //activity from USB or UI
bool screenOn = true;
uint16_t screenSaver = 0;

int8_t systemMenuSelection = 0;  
int8_t sysExSelection = 0;       
int8_t fxSelectedParam = 0;      
bool isEditingParam = false; 
bool inChannelMenu = true; //For saving menu redraw, resused from Channel Memu, should prob change to inMenu

// Global FX values
uint8_t masterVolumeState = 127; //Setup init values track SC-55 MkII (with screen)
uint8_t masterReverbState = 64;
uint8_t masterChorusState = 64;
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
void loop() {
    if (!(PINC & (1 << 7))) { tinyDelay(200); if (!(PINC & (1 << 7))) { // Direct read of Pin 10 (PC7)
    resetSystem(); }} // Delay for accidental button press
//  --- 1a. PC Host USB MIDI Input Handler ---
    while (usbMIDI.read()) { 
        uint8_t type    = usbMIDI.getType();
        // OPTIMIZATION: Drop Real-Time Clock flooding (synth doesn't need to sync tempo)
        if (type == 0xF8 || type == 0xFE) continue; //Go to loop start to process next packet immediately
        uint8_t channel = usbMIDI.getChannel();
        uint8_t d1      = usbMIDI.getData1();
        uint8_t d2      = usbMIDI.getData2();
        activity = true;

        if (type < 0xF0 ) {
            Serial1.write((type & 0xF0) | ((channel - 1) & 0x0F));
            Serial1.write(d1);
            if ((type & 0xF0) != 0xC0 && (type & 0xF0) != 0xD0) { 
                Serial1.write(d2);
            }
            // If it's Pitch Bend E0, Note On 90, Note Off 80, Aftertouch A0, or Ch Pressure D0, skip to next byte
            uint8_t statusNibble = type & 0xF0;
            if (statusNibble == 0xE0 || statusNibble == 0x90 || statusNibble == 0x80 || statusNibble == 0xA0 || statusNibble == 0xD0) {
                continue; }
         // 2. STATE INTERCEPT PATH (Only runs for specific UI parameters)
         if (type == usbMIDI.ControlChange) {
            
            switch (d1) { // Check CC parameters cleanly using an optimized switch & update if changed
                case 0:
                    chanCurrentBank[channel - 1] = d2; updateDisplayFlag = true; continue;
                case 7:
                    if (chanVolume[channel - 1] != d2) {chanVolume[channel - 1] = d2; updateDisplayFlag = true;
                } continue;
                case 91:
                    if (chanReverb[channel - 1] != d2) {chanReverb[channel - 1] = d2; updateDisplayFlag = true;
                } continue;
                case 93:
                    if (chanChorus[channel - 1] != d2) {chanChorus[channel - 1] = d2; updateDisplayFlag = true;
                } continue;
            }
         } 
         else if (type == usbMIDI.ProgramChange) {
            synchronizeUIWithIncomingPatch(channel, chanCurrentBank[channel - 1], d1);
         continue; }
        }    //  --- SysEX Display Packet Handling from USB & fall through for unprocessed MIDI bytes
         
    else if (type == usbMIDI.SystemExclusive) {
            const byte *sysExData = usbMIDI.getSysExArray();
            unsigned int sysExLen = d1 + (d2 * 256); 
            if (sysExLen != 74) Serial1.write(sysExData, sysExLen); // No 74 byte 16x16 graphic sent to SCB-55
         // Length>=10  0x41=Roland
         //             ch=10-1F Model:0x16=MT32 0x42/0x45=SC-55 
         //             0x12=command 0x20/0x18=MT/SC address (width=20chr)
        if (sysExLen <= 9) {
            // Put short SysEx checks here
                        if (sysExData[1] == 0x7E && sysExData[2] == 0x7F && sysExData[3] == 0x09 && sysExData[4] == 0x01) {
                        inboundReset(); return; }//gmReset received! 

            return;
        }

        // Inline validation: Check Vendor, Command, and Channel ID bounds in one step
        if (sysExData[1] != 0x41 || sysExData[4] != 0x12 || (uint8_t)(sysExData[2] - 0x10) > 0x0F) return;

        // Cache frequent memory lookups directly into CPU working registers
        uint8_t mID  = sysExData[3]; // Model MT-32 (0x16) / SC-55 / GM (0x42/0x45)
        uint8_t aHi  = sysExData[5]; // Address High
        uint8_t aMid = sysExData[6]; // Address Mid

        switch (mID) {
            case 0x16:
                if (aHi == 0x20) sysExTextLine(sysExData, sysExLen); //Move sysEx Text to screen variable
                break;

            case 0x42:
            // Drum Channel Bitmask Mapping Block
            // Validates: aHi (sysExData[5]) == 0x40, sysExData[7] == 0x15, and aMid (sysExData[6]) high nibble == 0x10
        if (aHi == 0x40 && sysExData[7] == 0x15 && (aMid & 0xF0) == 0x10) {
            
            // Dynamic Roland to standard MIDI channel conversion
            uint8_t ch = (aMid & 0x0F);
            ch = (ch == 0) ? 10 : (ch > 9) ? ch + 1 : ch;

            // Update 16-bit drum channel tracking map using the payload parameter value (sysExData[8])
            channelMap = (sysExData[8] > 0) ? (channelMap | (1U << (ch - 1))) : (channelMap & ~(1U << (ch - 1)));
            break; 
        }
            case 0x45: // Fall-through groups shared logic for fast execution
                if (aHi == 0x10) {
                    if (aMid == 0x00) {
                        sysExTextLine(sysExData, sysExLen); //Move sysEx Text to screen variable
                    } else if (sysExLen == 74 && aMid == 0x01 && sysExData[7] == 0x00) { // USB_MIDI_SYSEX_MAX 79 in usb_api.h
                        // Extract raw data chunk (pointer shifts past the 8 baseline header bytes)
                        injectPayloadToDisplayBuffer(sysExData + 8);
                    }
                } else if (mID == 0x42 && aHi == 0x40 && aMid == 0x00 && sysExData[7] == 0x7F && sysExData[8] == 0x00) {
                    inboundReset(); return; //gsReset received!
                }
                break;
        }

        } //end of SysEx
        Serial1.write(type); //If we missed anything, send it.
    } //end of While usbMIDI

 //  --- 1b. Hardware DIN Serial MIDI Pass-Through Merger ---
    static uint8_t serialMidiStatus = 0;
    static uint8_t serialMidiCount = 0;
    static uint8_t serialMidiD1 = 0;
    static uint8_t serialRxChan = 0;
    static uint8_t serialEat = 0; //for tracking serial bytes to skip & activity monitor
    bool parserIsIdle = true;

    while (Serial1.available() > 0) {
        uint8_t incomingByte = Serial1.read();
        //usbMIDI.send_now(); //To prevent buffer stall from disconnected USB MIDI

        // Drop Clock F8 FE, Start FA, Continue FB, Stop FC, Reset FF & the two undefined Real Time Bytes
        if (incomingByte >= 0xF8) { continue; } 
                
        if (incomingByte == MIDI_SYSEX_START || isRecordingSysEx) {
            processSysEx(incomingByte); continue; } 

        Serial1.write(incomingByte); //If no SysEx to process

            if (serialEat != 0) {serialEat--; continue;}
            switch (incomingByte & 0xF0) {
                case 0x80: serialEat = 2; continue; //Restart loop after (untracked) Note Off sent (pass & eat next two bytes)
                case 0x90: serialEat = 2; continue; //Restart loop after (untracked) Note On sent (pass & eat next two bytes)
                case 0xA0: serialEat = 2; continue; //Restart loop after (untracked) Aftertouch sent (pass & eat next two bytes)
                case 0xD0: serialEat = 1; continue; //Restart loop after (untracked) Ch Pressure sent (pass & eat next byte)
                case 0xE0: serialEat = 2; continue; //Restart loop after (untracked) Pitch Bend sent (pass & eat next two bytes)
            } 

    // 1. Process all available bytes in the hardware serial buffer
        parserIsIdle = false; // Parser is actively processing a stream
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
